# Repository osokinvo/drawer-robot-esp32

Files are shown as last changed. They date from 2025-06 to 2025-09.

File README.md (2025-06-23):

# Drawer Robot (esp32)

Этот проект представляет собой робота, который может рисовать простые изображения на плоскости с помощью ESP32.

## 🔧 Особенности

- Управление шаговыми моторами
- Интеграция с FreeRTOS

## 🧩 Используемые технологии

- ESP32 + FreeRTOS
- KiCad для проектирования платы
- 3D-печать корпуса

## 🚀 Установка

1. Скопируйте репозиторий
2. Откройте `firmware/` в PlatformIO или ESP-IDF
3. Скомпилируйте и загрузите на ESP32

## 📂 Структура

- `hardware/pcb/` — разводка и схема платы
- `hardware/3d-models/` — детали корпуса
- `firmware/` — код прошивки
- `docs/` — изображения, схемы

## 📜 Лицензия

Проект распространяется под лицензией MIT.

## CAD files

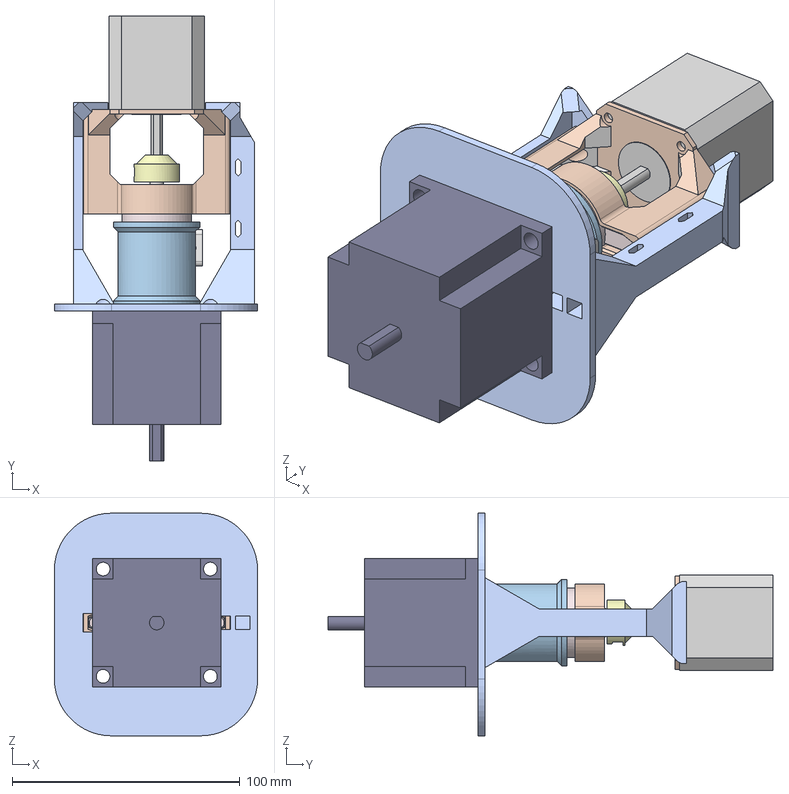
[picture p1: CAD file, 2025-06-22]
hardware/3d-models/Drum with brake.stp
89.3 x 195.5 x 97.8 mm
Барабан конический
Зажим каната
Муфта тормоза
Тормоз
Nema17
Nema23
Направляющая тормаза
Крпление двигателей UV
DIN 933 - M6 x 16

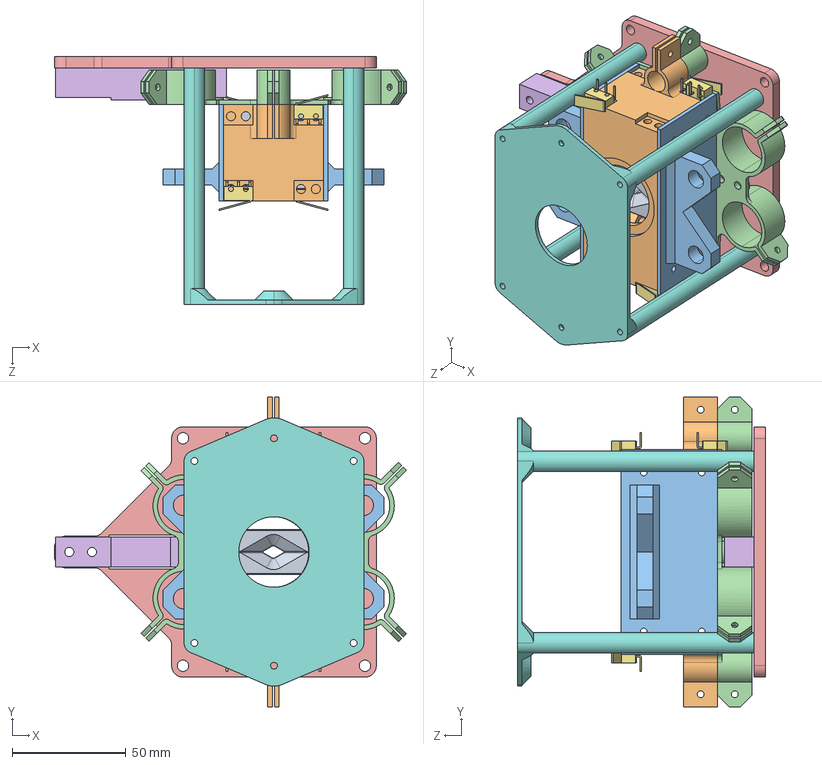
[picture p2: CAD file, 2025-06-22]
hardware/3d-models/Pencil carriage.STEP
154.8 x 136.1 x 109.0 mm
Прижим карандаша x 2
Каретка карандаша
Стенка каретки x 2
Опора двигателей карандаша
Опора каретки
Тензодатчик
micro-switch x 4
Крышка каретки

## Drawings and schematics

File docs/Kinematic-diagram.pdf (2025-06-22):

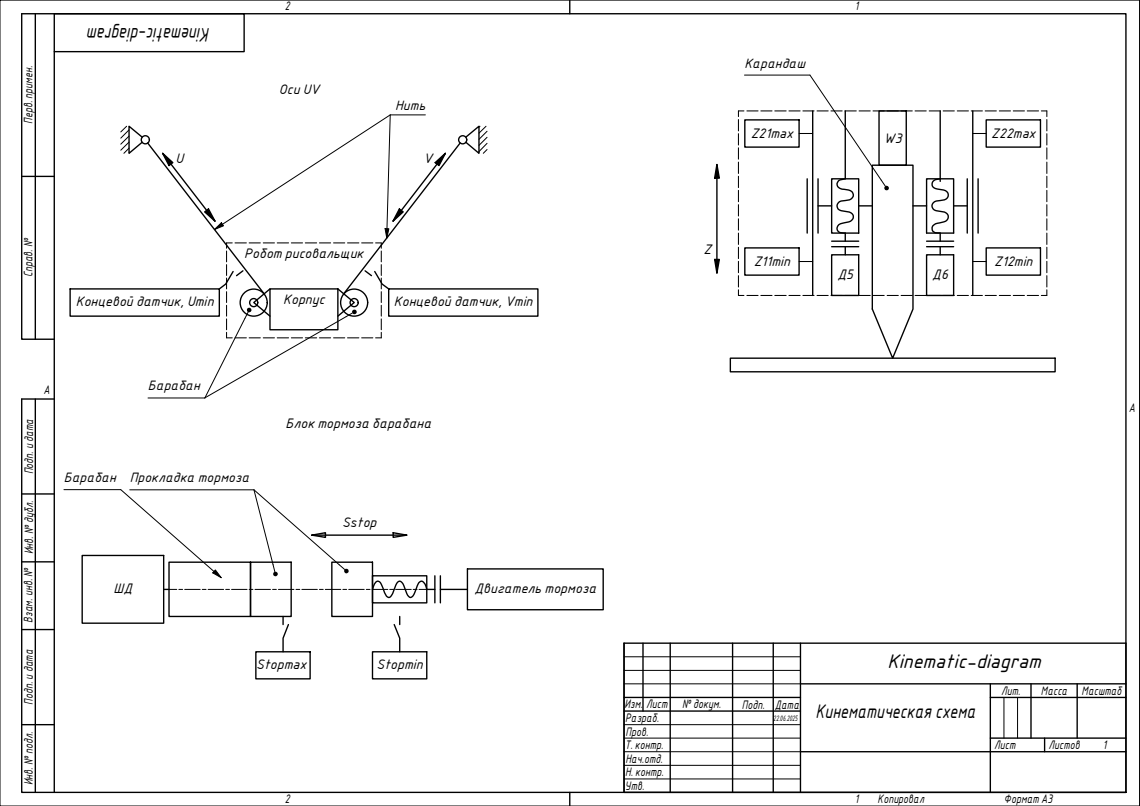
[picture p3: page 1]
Формат А3; Робот рисовальщик; Концевой датчик, Umin; Концевой датчик, Vmin; Оси UV; Двигатель тормоза; Инв. №; л. Под; бл. Под; Перв. п

Блок тормоза барабана

Барабан Прокладка тормоза

Kinematic-diagram

Кинематическая схема | Лит. | Масса | Масштаб

Изм. | Лист | № докум. | Подп. | Дата
Разраб. | | | | 22.06.2025
Пров.
Т. контр. | | | | | Лист | Листов 1
Нач.отд.
Н. контр.
Утв.

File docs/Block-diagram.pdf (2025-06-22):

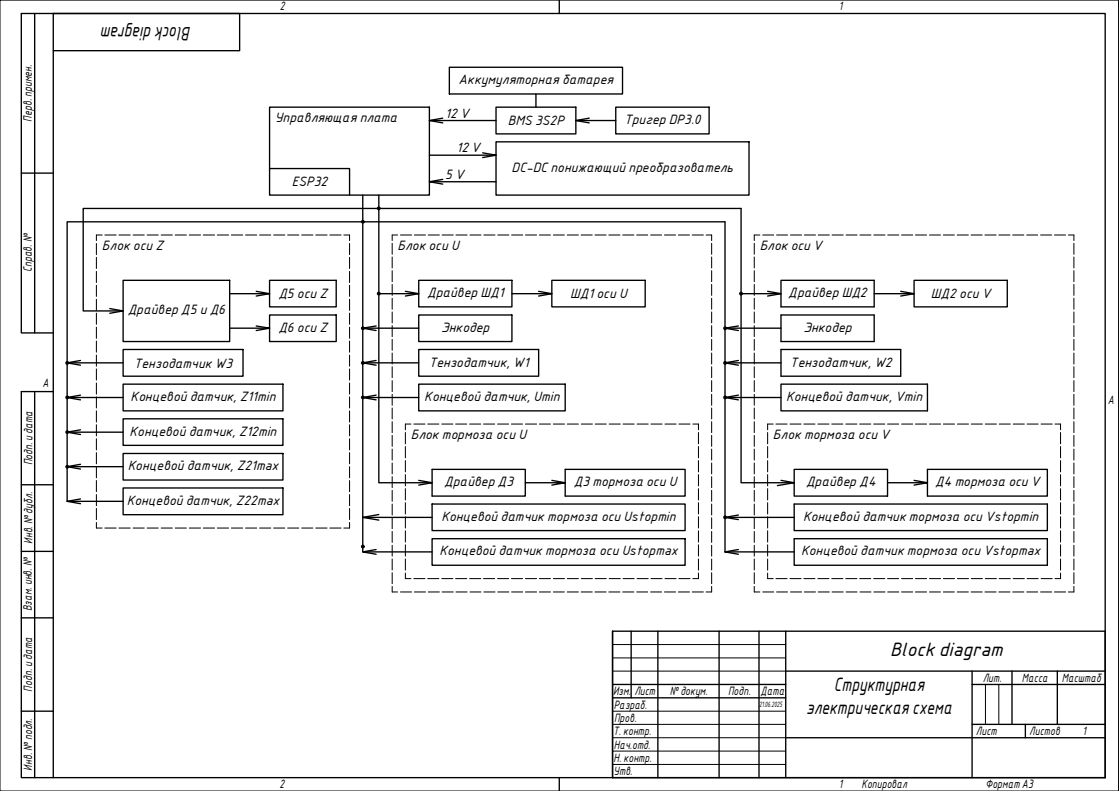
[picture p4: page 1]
Формат А3; Блок оси U; Драйвер ШД1; ШД1 оси U; Тензодатчик, W1; Драйвер Д3; Д3 тормоза оси U; ШД2 оси V; Тензодатчик, W2; Д4 тормоза оси V; Драйвер ШД2; Драйвер Д4; Блок оси V; Драйвер Д5 и Д6; Блок оси Z; Д5 оси Z; Д6 оси Z; Концевой датчик, Z11min; Концевой датчик, Z12min; Концевой датчик, Z21max; Концевой датчик, Z22max; Тензодатчик W3; BMS 3S2P; Тригер DP3.0; Управляющая плата; Аккумуляторная батарея; Инв. №; л. Под; бл. Под; Перв. п

DC-DC понижающий преобразователь

Концевой датчик, Umin

Концевой датчик, Vmin

Блок тормоза оси U

Блок тормоза оси V

Концевой датчик тормоза оси Ustopmin

Концевой датчик тормоза оси Vstopmin

Концевой датчик тормоза оси Ustopmax

Концевой датчик тормоза оси Vstopmax

Block diagram

Структурная электрическая схема | Лит. | Масса | Масштаб

Изм. | Лист | № докум. | Подп. | Дата
Разраб. | | | | 21.06.2025
Пров.
Т. контр. | | | | | Лист | Листов 1
Нач.отд.
Н. контр.
Утв.

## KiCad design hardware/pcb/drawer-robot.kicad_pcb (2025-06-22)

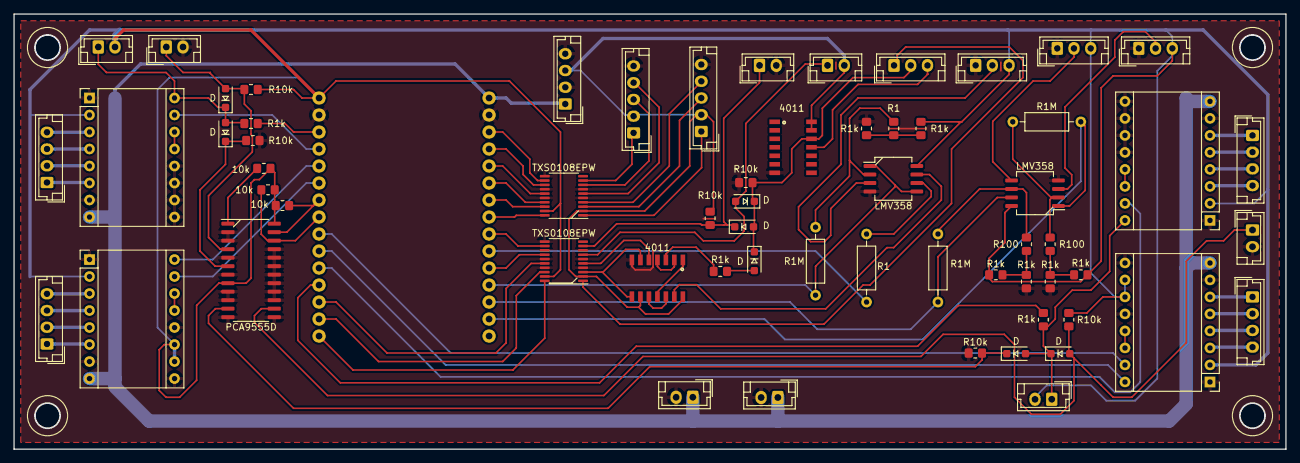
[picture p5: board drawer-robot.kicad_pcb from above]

Board: 2 copper layers, 190.0 x 65.0 mm, 63 parts (0 on the bottom side), 85 nets.

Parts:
A1, A2, A3, A4: Pololu_Breakout_A4988; Pololu_Breakout-16_15.2x20.3mm
D1, D2, D3, D4, D5, D6, D7: D; D_SOD-123F_dir
J1: ESP32 WROOM DevKit v1
J2, J3, J5, J7, J10: Conn_01x04_Pin; JST_EH_B4B-EH-A_1x04_P2.50mm_Vertical
J4, J6, J8, J9, J11, J12, J22, J23: Conn_01x02_Pin; JST_EH_B2B-EH-A_1x02_P2.50mm_Vertical
J16, J17: Conn_01x05_Pin; JST_EH_B5B-EH-A_1x05_P2.50mm_Vertical
J18, J19, J20, J21: Conn_01x03_Pin; JST_EH_B3B-EH-A_1x03_P2.50mm_Vertical
R1, R3, R30, R31, R34, R35, R38, R39, R42: R1k; R_0805_2012Metric_Pad1.20x1.40mm_HandSolder
R2, R4, R5, R6, R43, R44: R10k; R_0805_2012Metric_Pad1.20x1.40mm_HandSolder
R7: R1; R_Axial_DIN0207_L6.3mm_D2.5mm_P10.16mm_Horizontal
R10, R11, R12: 10k; R_0805_2012Metric_Pad1.20x1.40mm_HandSolder
R32, R36: R100; R_0805_2012Metric_Pad1.20x1.40mm_HandSolder
R33, R37, R41: R1M; R_Axial_DIN0207_L6.3mm_D2.5mm_P10.16mm_Horizontal
R40: R1; R_0805_2012Metric_Pad1.20x1.40mm_HandSolder
U1, U3: LMV358; SO-8_5.3x6.2mm_P1.27mm
U4, U5: 4011; SOP14
U6: PCA9555D; SO-24_5.3x15mm_P1.27mm
U7, U8: TXS0108EPW; TSSOP-20_4.4x6.5mm_P0.65mm

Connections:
+5V: J10.3, J16.2, J17.2, J22.2, R44.2, U4.9, U4.14 (VDD), U5.13, U5.14 (VDD), U7.2 (VCCA), U8.2 (VCCA)
+12V: A1.8 (VMOT), A2.8 (VMOT), A3.8 (VMOT), A4.8 (VMOT), J1.1 (VIN), J10.1, J11.1, J12.1
A1: J1.7 (A9), U7.18 (B2)
A1_10k: J1.14 (VP), R33.1, U1.1
A2: J1.4 (GPIO12), U7.13 (B7)
A2_10k: J1.13 (VN), R37.1, U1.7
AZ_10M: J1.12 (A6), R41.1, U3.1, U3.5 (+)
B1: J1.8 (A8), U7.20 (B1)
B2: J1.3 (GPIO13), U7.12 (B8)
BRAKE_SD1_DIR: J1.18 (GPIO15), R3.1
BRAKE_SD1_STEP: A3.15 (STEP), J1.19 (GPIO2)
BRAKE_SD2_DIR: J1.27 (RX0), R1.1
BRAKE_SD2_STEP: A4.15 (STEP), J1.26 (GPIO21)
Clock2_Pin: J1.23 (GPIO5), R12.1, U6.22 (SCL)
Data2_Pin: J1.22 (TX2), R11.1, U6.23 (SDA)
EN_LOG_Z: J1.29 (GPIO22), U8.18 (B2)
EN_LOG_Z5V: U4.6, U4.8, U8.3 (A2)
FEEDBACK_Z5V: U3.7, U4.13
GND: A1.1 (GND), A1.7 (GND), A1.9 (~ENABLE), A1.12 (MS3), A2.1 (GND), A2.7 (GND), A2.9 (~ENABLE), A2.12 (MS3), A3.1 (GND), A3.7 (GND), A3.9 (~ENABLE), A3.10 (MS1), A3.11 (MS2), A3.12 (MS3), A4.1 (GND), A4.7 (GND), A4.9 (~ENABLE), A4.10 (MS1), A4.11 (MS2), A4.12 (MS3), J1.2 (GND), J1.17 (GND), J6.2, J9.2, J10.2, J10.4, J11.2, J12.2, J16.5, J17.5, J18.1, J19.1, J20.1, J23.2, R2.2, R5.2, R31.1, R35.1, R39.1, R43.2, U1.4 (V-), U3.4 (V-), U4.7 (VSS), U5.7 (VSS), U6.2 (A1), U6.3 (A2), U6.5 (IO0_1), U6.7 (IO0_3), U6.9 (IO0_5), U6.10 (IO0_6), U6.12 (VSS), U6.13 (IO1_0), U6.15 (IO1_2), U6.16 (IO1_3), U6.17 (IO1_4), U6.18 (IO1_5), U6.19 (IO1_6), U6.20 (IO1_7), U6.21 (A0), U7.5 (A4), U7.7 (A6), U7.11 (GND), U7.14 (B6), U7.16 (B4), U8.4 (A3), U8.6 (A5), U8.8 (A7), U8.11 (GND), U8.13 (B7), U8.15 (B5), U8.17 (B3)
LOG_AZ_10M: J1.10 (A4), R7.1
LOG_Z5V: U4.5, U8.5 (A4)
LOG_Z_DIR: J1.28 (TX0), U8.16 (B4)
unnamed: A1.4 (1A), J5.3
unnamed: A1.3 (1B), J5.4
unnamed: A1.5 (2A), J5.2
unnamed: A1.6 (2B), J5.1
unnamed: A1.13 (~RESET), A1.14 (~SLEEP)
unnamed: A2.4 (1A), J2.3
unnamed: A2.3 (1B), J2.4
unnamed: A2.5 (2A), J2.2
unnamed: A2.6 (2B), J2.1
unnamed: A2.13 (~RESET), A2.14 (~SLEEP)
unnamed: A3.4 (1A), J7.3
unnamed: A3.3 (1B), J7.4
unnamed: A3.5 (2A), J7.2
unnamed: A3.6 (2B), J7.1
unnamed: A3.16 (DIR), D1.1 (K), D3.2 (A), J8.1, R3.2
unnamed: A3.13 (~RESET), A3.14 (~SLEEP)
unnamed: A4.4 (1A), J3.3
unnamed: A4.3 (1B), J3.4
unnamed: A4.5 (2A), J3.2
unnamed: A4.6 (2B), J3.1
unnamed: A4.16 (DIR), D5.2 (A), D7.1 (K), J4.1, R1.2
unnamed: A4.13 (~RESET), A4.14 (~SLEEP)
unnamed: D2.2 (A), D4.1 (K), D6.1 (K), J21.2, R43.1, U5.12
unnamed: D4.2 (A), R42.2
unnamed: J16.1, U7.1 (A1)
unnamed: J16.3, U7.3 (A2)
unnamed: J16.4, U7.4 (A3)
unnamed: J17.1, U7.9 (A8)
unnamed: J17.3, U7.8 (A7)
unnamed: J17.4, U7.6 (A5)
unnamed: J18.2, U1.3 (+)
unnamed: J19.2, U1.5 (+)
unnamed: J20.2, U3.3 (+)
unnamed: J21.3, U5.11
unnamed: R30.1, R31.2, R32.2
unnamed: R34.1, R35.2, R36.2
unnamed: R38.1, R39.2, R40.2
unnamed: R32.1, R33.2, U1.2 (-)
unnamed: R36.1, R37.2, U1.6 (-)
unnamed: R40.1, R41.2, U3.2 (-)
unnamed: R7.2, U3.6 (-)
unnamed: U4.1, U4.11
unnamed: U4.2, U4.4
unnamed: U4.10, U4.12
SD1_DIR: A1.16 (DIR), J1.20 (GPIO4)
SD1_STEP: A1.15 (STEP), J1.21 (RX2)
SD2_DIR: A2.16 (DIR), J1.25 (GPIO19)
SD2_STEP: A2.15 (STEP), J1.24 (GPIO18)
STOP_SD1_MAX: D3.1 (K), R5.1, U6.6 (IO0_2)
STOP_SD1_MIN: D1.2 (A), J9.1, R4.1, U6.4 (IO0_0)
STOP_SD2_MAX: D5.1 (K), R2.1, U6.11 (IO0_7)
STOP_SD2_MIN: D7.2 (A), J6.1, R6.1, U6.14 (IO1_1)
STOP_Z_MAX: J1.9 (A5), U8.12 (B8)
STOP_Z_MAX5V: D6.2 (A), J22.1, U8.7 (A6)
STOP_Z_MIN: J1.11 (A7), U8.14 (B6)
STOP_Z_MIN5V: D2.1 (K), J23.1, R44.1, U8.9 (A8)
VDD3V3: A1.2 (VDD), A1.10 (MS1), A1.11 (MS2), A2.2 (VDD), A2.10 (MS1), A2.11 (MS2), A3.2 (VDD), A4.2 (VDD), J1.16 (VDD3V3), J4.2, J8.2, J18.3, J19.3, J20.3, R4.2, R6.2, R10.2, R11.2, R12.2, R30.2, R34.2, R38.2, U1.8 (V+), U3.8 (V+), U6.8 (IO0_4), U6.24 (VDD), U7.19 (VCCB), U8.19 (VCCB)
X1: J1.6 (GPIO27), U7.17 (B3)
X2: J1.5 (GPIO14), U7.15 (B5)
Z_DIR: R42.1, U4.3
Z_VEL: J1.30 (GPIO23), U8.20 (B1)
Z_VEL5V: J21.1, U8.1 (A1)
~INT2: R10.1, U6.1 (~INT)

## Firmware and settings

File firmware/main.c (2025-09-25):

//Этот файл содержит основную функцию setup() и loop(), которые вызываются при запуске программы. В этом файле можно разместить код, который инициализирует контроллер, устанавливает соединение с WiFi и запускает основной цикл программы.


// Глобальные переменные
QueueHandle_t gCodeQueue;
SemaphoreHandle_t mutex;

void setup() {
  
  esp_log_level_set("*", ESP_LOG_INFO);
  LOGI("main", "Controller started");

  wifi_main(void);

  // Создание задачи для приема G-кода
  xTaskCreate(receiveGCodeTask, "Receive G-Code", 2048, NULL, 2, NULL);

  // Создание задачи для отправки статуса робота
  xTaskCreate(sendStatusTask, "Send Status", 2048, NULL, 2, NULL);

  // Создание задачи для управления шаговыми двигателями
  xTaskCreate(stepMotorTask, "Step Motor", 2048, NULL, 2, NULL);

  // Создание задачи для управления двигателями постоянного тока
  xTaskCreate(dcMotorTask, "DC Motor", 2048, NULL, 2, NULL);

  // Создание задачи для чтения концевых датчиков
  xTaskCreate(readSensorTask, "Read Sensor", 2048, NULL, 2, NULL);

  // Создание задачи для чтения аналоговых сигналов от датчиков веса
  xTaskCreate(readWeightTask, "Read Weight", 2048, NULL, 2, NULL);

  // Создание задачи для чтения данных с энкодеров
  xTaskCreate(readEncoderTask, "Read Encoder", 2048, NULL, 2, NULL);
}

void loop() {
  // Пустой цикл
}

void receiveGCodeTask(void* pvParameters) {
  while (1) {
    // Получение G-кода по WiFi
    String gCode = receiveGCode();
    // Обработка G-кода
    processGCode(gCode);
    // Отправка статуса робота
    sendStatus();
    vTaskDelay(100);
  }
}

void sendStatusTask(void* pvParameters) {
  while (1) {
    // Отправка статуса робота по WiFi
    sendStatus();
    vTaskDelay(1000);
  }
}

void stepMotorTask(void* pvParameters) {
  while (1) {
    // Управление шаговыми двигателями
    controlStepMotors();
    vTaskDelay(10);
  }
}

void dcMotorTask(void* pvParameters) {
  while (1) {
    // Управление двигателями постоянного тока
    controlDcMotors();
    vTaskDelay(10);
  }
}

void readSensorTask(void* pvParameters) {
  while (1) {
    // Чтение концевых датчиков
    readSensors();
    vTaskDelay(10);
  }
}

void readWeightTask(void* pvParameters) {
  while (1) {
    // Чтение аналоговых сигналов от датчиков веса
    readWeights();
    vTaskDelay(10);
  }
}

void readEncoderTask(void* pvParameters) {
  while (1) {
    // Чтение данных с энкодеров
    readEncoders();
    vTaskDelay(10);
  }
}

void receiveGCode() {
  // Получение G-кода по WiFi
  WiFiClient client;
  client.connect("your_server_ip", 80);
  client.println("GET /gcode HTTP/1.1");
  client.println("Host: your_server_ip");
  client.println("Connection: close");
  client.println();
  delay(100);
  String gCode = client.readString();
  client.stop();
  return gCode;
}

void processGCode(String gCode) {
  // Обработка G-кода
  // ...
}

void sendStatus() {
  // Отправка статуса робота по WiFi
  WiFiClient client;
  client.connect("your_server_ip", 80);
  client.println("POST /status HTTP/1.1");
  client.println("Host: your_server_ip");
  client.println("Content-Type: application/json");
  client.println("Content-Length: " + String(getStatus().length()));
  client.println();
  client.print(getStatus());
  client.stop();
}

String getStatus() {
  // Получение статуса робота
  // ...
  return "status";
}

void controlStepMotors() {
  // Управление шаговыми двигателями
  // ...
}

void controlDcMotors() {
  // Управление двигателями постоянного тока
  // ...
}

void readSensors() {
  // Чтение концевых датчиков
  // ...
}

void readWeights() {
  // Чтение аналоговых сигналов от датчиков веса
  // ...
}

void readEncoders() {
  // Чтение данных с энкодеров
  // ...
}

void main() {
  

}

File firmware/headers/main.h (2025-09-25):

#ifndef MAIN_H
#define MAIN_H

#include <ctype.h>
#include <queue.h>
#include <math.h>
#include <semphr.h>
#include <stdio.h>
#include <string.h>
#include <stdlib.h>
#include <task.h>
#include <WiFi.h>

#include "driver/gpio.h"
#include "driver/pcnt.h"
// #include "driver/sdmmc_host.h" // TF-card (закомментировано)
#include "esp_timer.h"
#include "esp_wifi.h"
#include "esp_event.h"
#include "esp_netif.h"
#include "esp_spiffs.h"
#include "esp_system.h"
#include "esp_websocket_client.h"
#include "nvs_flash.h"
#include "mdns.h"
#include <FreeRTOS.h>
#include "freertos/FreeRTOS.h"
#include "freertos/task.h"
#include "freertos/queue.h"
// #include "sdmmc_cmd.h" // TF-card (закомментировано)

#include "encoder.h"
#include "force_measurement.h"
#include "gcode.h"
#include "motor.h"
#include "spiffs.h"
#include "wifi.h"

#define ENABLE_DEBUG_LOGS 1

#if ENABLE_DEBUG_LOGS

#include "esp_log.h"
#define LOGI(tag, ftm, ...) ESP_LOGI(tag, ftm, ##__VA_ARGS__)
#define LOGW(tag, ftm, ...) ESP_LOGW(tag, ftm, ##__VA_ARGS__)
#define LOGE(tag, ftm, ...) ESP_LOGE(tag, ftm, ##__VA_ARGS__)

#else

#define LOGI(tag, ftm, ...) {}
#define LOGW(tag, ftm, ...) {}
#define LOGE(tag, ftm, ...) {}

#endif


// =============================================
// Аналоговые входы (ADC1, 12-бит)
// =============================================
#define U_AXIS_FORCE_ADC_CHANNEL    ADC1_CHANNEL_0  // GPIO36 - Вход усилия по оси U (операционный усилитель)
#define V_AXIS_FORCE_ADC_CHANNEL    ADC1_CHANNEL_3  // GPIO39 - Вход усилия по оси V (операционный усилитель)
#define Z_AXIS_FORCE_ADC_CHANNEL    ADC1_CHANNEL_6  // GPIO34 - Вход усилия по оси Z (операционный усилитель)

// =============================================
// Аналоговый выход (DAC, 8-бит)
// =============================================
#define Z_AXIS_FORCE_DAC_CHANNEL    DAC_CHANNEL_1    // GPIO32 - ЦАП для задания усилия по оси Z

// =============================================
// Цифровые входы 
// =============================================
#define Z_AXIS_LIMIT_MAX_PIN        35  // GPIO35 - Концевой датчик max положения оси Z
#define Z_AXIS_LIMIT_MIN_PIN        33  // GPIO33 - Концевой датчик min положения оси Z

// =============================================
// Энкодеры (цифровые входы)
// =============================================
#define U_AXIS_ENC_A_PIN            25  // GPIO25 - Фаза A энкодера оси U
#define U_AXIS_ENC_B_PIN            26  // GPIO26 - Фаза B энкодера оси U
#define U_AXIS_ENC_X_PIN            27  // GPIO27 - Индексный сигнал энкодера оси U

#define V_AXIS_ENC_A_PIN            12  // GPIO12 - Фаза A энкодера оси V
#define V_AXIS_ENC_B_PIN            14  // GPIO14 - Фаза B энкодера оси V
#define V_AXIS_ENC_X_PIN            13  // GPIO13 - Индексный сигнал энкодера оси V

#if ENABLE_DEBUG_LOGS == 0

// =============================================
// Управление двигателями (ШИМ/цифровые выходы)
// =============================================
#define Z_AXIS_MOTOR_PWM_PIN        23  // GPIO23 - ШИМ сигнал скорости двигателя оси Z
#define Z_AXIS_MOTOR_CTRL_PIN       22  // GPIO22 - Сигнал включения двигателя оси Z
#define Z_AXIS_MOTOR_DIR_PIN         1  // GPIO1  - Направление вращения двигателя оси Z

#endif

// =============================================
// Управление осью U (цифровые выходы)
// =============================================
#define U_AXIS_MOTOR_STEP_PIN      16  // GPIO16 - Шаг двигателя оси U
#define U_AXIS_MOTOR_DIR_PIN        4  // GPIO4  - Направление двигателя оси U
#define U_AXIS_BRAKE_STEP_PIN       2  // GPIO2  - Шаг тормоза оси U
#define U_AXIS_BRAKE_DIR_PIN       15  // GPIO15 - Направление тормоза оси U

#if ENABLE_DEBUG_LOGS == 0

// =============================================
// Управление осью V (цифровые выходы)
// =============================================
#define V_AXIS_BRAKE_DIR_PIN         3  // GPIO3  - Направление тормоза оси V
#define V_AXIS_BRAKE_STEP_PIN       21  // GPIO21 - Шаг управления тормозом оси V
#define V_AXIS_MOTOR_DIR_PIN        19  // GPIO19 - Направление двигателя оси V
#define V_AXIS_MOTOR_STEP_PIN       18  // GPIO18 - Шаг двигателя оси V

#endif

// =============================================
// I2C (датчики/дисплей)
// =============================================
#define I2C_SCL_PIN                 5  // GPIO5  - Тактовая линия I2C
#define I2C_SDA_PIN                17  // GPIO17 - Линия данных I2C

// =============================================
// Конфигурация PCA9555D
// =============================================
#define PCA9555_ADDR         0x20      // Базовый адрес (A0=A1=A2=GND)
#define PCA9555_INPUT_REG_0  0x00      // Регистр ввода PORT0
#define PCA9555_INPUT_REG_1  0x01      // Регистр ввода PORT1
#define PCA9555_CONFIG_REG_0 0x06      // Регистр конфигурации PORT0 (1=input)
#define PCA9555_CONFIG_REG_1 0x07      // Регистр конфигурации PORT1 (1=input)
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

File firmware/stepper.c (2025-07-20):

// Этот файл содержит функции, которые управляют шаговыми двигателями, такие как функции для управления скоростью, направлением и т. д.


#include "main.h"

int lock_axis(RobotParams *params, int step_pin, int dir_pin, int *brake_flag) {
// Locks the axis by closing the mechanical brake.
// The function checks the state of the brake flag and changes the signals on
// the pins to unlock the axle.

// @param params Pointer to the structure containing the parameters of the
//               robot.
// @param step_pin The pin connected to the step of the motor.
// @param dir_pin The pin connected to the direction of the motor.
// @param brake_flag Pointer to the brake flag of the motor.
//
// @return OK if the axis was successfully locked, otherwise an error code.
    get_brake_flags(params);
    if (*brake_flag != True){
        gpio_set_level(dir_pin, CLOSE_BRAKE_DIR);
        while (*brake_flag != True){
            gpio_set_level(step_pin, HIGH);
            delayMicroseconds(STEP_MIN_PERIOD);
            gpio_set_level(step_pin, LOW);
            delayMicroseconds(params->step_low_brake);
            get_brake_flags(params);
        }
    }
    return OK;
}

int unlock_axis(RobotParams *params, int step_pin, int dir_pin, int *brake_flag) {
// Разблокирует ось, открывая механический тормоз.
// Функция проверяет состояние флага тормоза и изменяет сигналы на пинах, чтобы
// разблокировать ось.
//
// @param params Указатель на структуру с параметрами робота.
// @param step_pin Пин, на котором подключен шаг двигателя тормоза.
// @param dir_pin Пин, на котором подключен сигнал направления двигателя тормоза.
// @param brake_flag Указатель на флаг открытия тормоза.
//  
// @return OK Возвращает OK, когда ось успешно разблокируется.
    get_brake_flags(params);
    if (*brake_flag != True){
        gpio_set_level(dir_pin, OPEN_BRAKE_DIR);
        while (*brake_flag != True){
            gpio_set_level(step_pin, HIGH);
            delayMicroseconds(STEP_MIN_PERIOD);
            gpio_set_level(step_pin, LOW);
            delayMicroseconds(params->step_low_brake);
            get_brake_flags(params);
        }
    }
    return OK;
}

static void motor_control_step(motor_control_t* motor) {
    // Считаем ошибку между планом и энкодером
    float error = motor->planned_position_steps - motor->encoder_position_steps * MOTOR_STEP_PER_RATATION / ENCODER_STEP_PER_RATATION;

    // Коррекция скорости по отставанию/опережению
    if (error > 0.0f) {
        // Двигатель отстаёт — ускоряемся
        if (motor->speed_adjustment < MAX_ADJUSTMENT)
            motor->speed_adjustment += ADJUSTMENT_STEP;
    } else if (error < 0.0f) {
        // Двигатель опережает — замедляемся
        if (motor->speed_adjustment > -MAX_ADJUSTMENT)
            motor->speed_adjustment -= ADJUSTMENT_STEP;
    }

    // Задержка между шагами с учётом коррекции
    float delay_us = motor->base_step_delay_us * (1.0f - motor->speed_adjustment);

    // Отправляем шаг
    gpio_set_level(motor->step_pin, 1);
}

int position_control_stepper(motor_control_t *motor, int prev_speed, int accel) {
    // Задать направление на основе цели
    if (motor->target_position > motor->planned_position)
        motor->direction = 1;
    else
        motor->direction = -1;

    // Шагаем до достижения цели
    while ((motor->direction > 0 && motor->planned_position < motor->target_position) ||
           (motor->direction < 0 && motor->planned_position > motor->target_position)) {
        motor->step_delay_us = 10000000 / prev_speed;
        motor_control_step(motor);
        motor->planned_position += motor->direction;
        prev_speed += accel * motor->step_delay_us / 1000000;
    }

    return OK;
}

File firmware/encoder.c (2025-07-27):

// Этот файл содержит функции, которые работают с энкодерами, такие как функции для чтения данных с энкодеров и т. д.

#include "main.h"

static void IRAM_ATTR encoder_isr_handler(void* arg) {
    encoder_t* encoder = (encoder_t*)arg;
    
    // Читаем текущее состояние
    uint8_t new_state = (gpio_get_level(encoder->pin_a) << 1) | 
                        gpio_get_level(encoder->pin_b);
    
    // Определяем направление
    encoder->motor->encoder_position_steps += gray_transitions[encoder->prev_state][new_state];;
    
    encoder->prev_state = new_state;
}

// Инициализация энкодера
void encoder_init(encoder_t* enc, gpio_num_t pin_a, gpio_num_t pin_b) {
    enc->pin_a = pin_a;
    enc->pin_b = pin_b;
    enc->count = 0;
    enc->prev_state = 0;

    // Настройка GPIO
    gpio_config_t io_conf = {
        .pin_bit_mask = (1ULL << pin_a),
        .mode = GPIO_MODE_INPUT,
        .intr_type = GGPIO_INTR_POSEDGE,
        .pull_up_en = GPIO_PULLUP_ENABLE
    };
    gpio_config(&io_conf);

    io_conf.pin_bit_mask = (1ULL << pin_b);
    io_conf.mode = GPIO_MODE_INPUT;
    io_conf.intr_type = GGPIO_INTR_POSEDGE;
    io_conf.pull_up_en = GPIO_PULLUP_ENABLE;
    gpio_config(&io_conf);

    // Регистрация обработчика с передачей указателя на структуру
    gpio_isr_handler_add(pin_a, encoder_isr_handler, enc);
    gpio_isr_handler_add(pin_b, encoder_isr_handler, enc);
}

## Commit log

2025-06-22 add control board
    [Drum with brake.stp, Pencil carriage.STEP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]
2025-06-23 Add component list
    [Components-list.csv]
2025-07-05 Add function for brake motor
2025-07-13 Add function with motor and encoder
2025-07-20 Add encoder functions
